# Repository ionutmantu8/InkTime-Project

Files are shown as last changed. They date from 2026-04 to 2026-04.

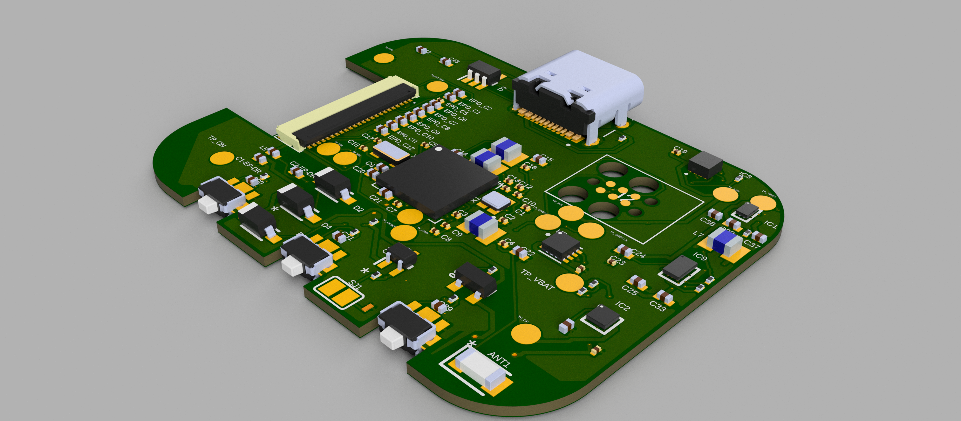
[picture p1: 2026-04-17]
Images/InkTime_3D-PCB_All_3D_1.png

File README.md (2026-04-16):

## Block Diagram
The system is built around the nRF52840 microcontroller, powered from a LiPo battery with USB-C charging, and integrates an e-paper display, IMU, fuel gauge, haptic driver, and three user buttons.

> If the block diagram does not render in your local Markdown viewer, open this file in VS Code and install the **Markdown Preview Mermaid Support** extension.

```mermaid
flowchart LR
    subgraph Power
        USB[USB-C]
        CHG[BQ25180<br/>LiPo Charger]
        BAT[LiPo Battery]
        DCDC[RT6160<br/>DC/DC]
        FG[MAX17048<br/>Fuel Gauge]
    end

    subgraph Core
        MCU[nRF52840]
        ANT[2450AT18B100E<br/>Antenna]
        SWD[SWD Header]
        IMU[BMA421 IMU]
    end

    subgraph Display
        EPDDRV[E-Paper Drive Circuit]
        EPDCONN[503480-2400<br/>E-Paper Connector]
        EPD[E-Paper Display]
    end

    subgraph UI
        BTN[3 Buttons]
        HAPTICDRV[DRV2605<br/>Haptic Driver]
        VIB[Shaker]
    end

    USB --> CHG --> BAT
    BAT --> DCDC
    BAT --> FG
    USB --> MCU
    DCDC --> MCU

    MCU --> ANT
    MCU --> SWD
    MCU <-->|I2C| IMU
    MCU <-->|I2C| FG

    MCU -->|SPI + EPD_CTRL| EPDDRV
    EPDDRV --> EPDCONN --> EPD

    MCU -->|GPIO| BTN
    MCU -->|I2C + HAPTIC_EN| HAPTICDRV
    HAPTICDRV --> VIB
```

## Bill of Materials (BOM)

|Component|JLC Part #|Package|Description|Datasheet|
| :--- | :--- | :--- | :--- | :--- |
|SJ1|N/A|Solder Jumper (Copper feature - leave open)|SMD solder JUMPER|N/A|
|R2, R3, R4|[C3920633](https://www.lcsc.com/product-detail/C3920633.html)|0201|7.68k 0201 Thin Film Surface Mount Fixed Resistor +/-0.5% 0.031W CPF0201D7K68C1|[datasheet](https://wmsc.lcsc.com/wmsc/upload/file/pdf/v2/lcsc/2404081048_TE-Connectivity-CPF0201B511RE1_C3920633.pdf)|
|C23, C27, C34, C42|[C21012218](https://www.lcsc.com/product-detail/C21012218.html)|-|Check availability|[datasheet](https://jlc-prod-smt.oss-eu-central-1.aliyuncs.com/smtDataManualFile/8603520985945550848-C21012218.pdf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)|
|EPD_C5|[C9900156064](https://www.lcsc.com/product-detail/C9900156064.html)|201|Generic chip capacitor|[datasheet](https://ds.yuden.co.jp/TYCOMPAS/or/download?pn=MLAST063SCG681JFNA01&fileType=CA)|
|R1_EP_DR|[C3920633](https://www.lcsc.com/product-detail/C3920633.html)|0201|7.68k 0201 Thin Film Surface Mount Fixed Resistor +/-0.5% 0.031W CPF0201D7K68C1|[datasheet](https://wmsc.lcsc.com/wmsc/upload/file/pdf/v2/lcsc/2404081048_TE-Connectivity-CPF0201B511RE1_C3920633.pdf)|
|C15|[C9900156064](https://www.lcsc.com/product-detail/C9900156064.html)|201|Generic chip capacitor|[datasheet](https://ds.yuden.co.jp/TYCOMPAS/or/download?pn=MLAST063SCG681JFNA01&fileType=CA)|
|C5, C7, C8, C12, C19|[C9900156064](https://www.lcsc.com/product-detail/C9900156064.html)|201|Generic chip capacitor|[datasheet](https://ds.yuden.co.jp/TYCOMPAS/or/download?pn=MLAST063SCG681JFNA01&fileType=CA)|
|C11|[C9900156064](https://www.lcsc.com/product-detail/C9900156064.html)|201|Generic chip capacitor|[datasheet](https://ds.yuden.co.jp/TYCOMPAS/or/download?pn=MLAST063SCG681JFNA01&fileType=CA)|
|R2_EP_DR, R9, R_PWR_EPD|[C3920633](https://www.lcsc.com/product-detail/C3920633.html)|0201|7.68k 0201 Thin Film Surface Mount Fixed Resistor +/-0.5% 0.031W CPF0201D7K68C1|[datasheet](https://wmsc.lcsc.com/wmsc/upload/file/pdf/v2/lcsc/2404081048_TE-Connectivity-CPF0201B511RE1_C3920633.pdf)|
|R5, R7, R8|[C3920633](https://www.lcsc.com/product-detail/C3920633.html)|0201|7.68k 0201 Thin Film Surface Mount Fixed Resistor +/-0.5% 0.031W CPF0201D7K68C1|[datasheet](https://wmsc.lcsc.com/wmsc/upload/file/pdf/v2/lcsc/2404081048_TE-Connectivity-CPF0201B511RE1_C3920633.pdf)|
|C1-EP-DR|[C9900156064](https://www.lcsc.com/product-detail/C9900156064.html)|201|Generic chip capacitor|[datasheet](https://ds.yuden.co.jp/TYCOMPAS/or/download?pn=MLAST063SCG681JFNA01&fileType=CA)|
|C24, C39|[C9900179830](https://www.lcsc.com/product-detail/C9900179830.html)|402|0402 (1005 Metric)|N/A|
|L2|[C12669](https://www.lcsc.com/product-detail/C12669.html)|402|Generic chip inductor|[datasheet](https://www.lcsc.com/datasheet/lcsc_datasheet_2304140030_Murata-Electronics-LQG15HS27NJ02D_C12669.pdf)|
|C1, C2, C17, C18|[C9900156064](https://www.lcsc.com/product-detail/C9900156064.html)|201|Generic chip capacitor|[datasheet](https://ds.yuden.co.jp/TYCOMPAS/or/download?pn=MLAST063SCG681JFNA01&fileType=CA)|
|L3|[C12669](https://www.lcsc.com/product-detail/C12669.html)|402|Generic chip inductor|[datasheet](https://www.lcsc.com/datasheet/lcsc_datasheet_2304140030_Murata-Electronics-LQG15HS27NJ02D_C12669.pdf)|
|C3, C4|[C9900156064](https://www.lcsc.com/product-detail/C9900156064.html)|201|Generic chip capacitor|[datasheet](https://ds.yuden.co.jp/TYCOMPAS/or/download?pn=MLAST063SCG681JFNA01&fileType=CA)|
|C29, C30, C31, C32, C37, C38|[C3920633](https://www.lcsc.com/product-detail/C3920633.html)|0201|7.68k 0201 Thin Film Surface Mount Fixed Resistor +/-0.5% 0.031W CPF0201D7K68C1|[datasheet](https://wmsc.lcsc.com/wmsc/upload/file/pdf/v2/lcsc/2404081048_TE-Connectivity-CPF0201B511RE1_C3920633.pdf)|
|EPD_C1, EPD_C2, EPD_C6, EPD_C7, EPD_C8, EPD_C9, EPD_C10, EPD_C11, EPD_C12|[C9900156064](https://www.lcsc.com/product-detail/C9900156064.html)|201|Generic chip capacitor|[datasheet](https://ds.yuden.co.jp/TYCOMPAS/or/download?pn=MLAST063SCG681JFNA01&fileType=CA)|
|R_TYPE_SEL|[C3920633](https://www.lcsc.com/product-detail/C3920633.html)|0201|7.68k 0201 Thin Film Surface Mount Fixed Resistor +/-0.5% 0.031W CPF0201D7K68C1|[datasheet](https://wmsc.lcsc.com/wmsc/upload/file/pdf/v2/lcsc/2404081048_TE-Connectivity-CPF0201B511RE1_C3920633.pdf)|
|SW_DN, SW_ENT, SW_UP|[C569760](https://www.lcsc.com/product-detail/C569760.html)|SMD,3.9x2.9mm|-40℃~+85℃ 1.6N 1.6mm 15V 2.9mm 20mA 3.9mm 500,000 Cycles IP67 J-Lead Rectangular Button SPST Surface Mount,Vertical White With Bracket SMD,3.9x2.9mm Tactile Switches ROHS|[datasheet](https://wmsc.lcsc.com/wmsc/upload/file/pdf/v2/lcsc/2301111010_PANASONIC-EVPAKE31A_C569760.pdf)|
|Q1|[C2564](https://www.lcsc.com/product-detail/C2564.html)|TO-220AB|-55℃~+175℃ 1 P-Channel 180nC@10V 200W 20mΩ@10V 3.4nF 4V 55V 640pF 74A P-Channel TO-220AB MOSFETs ROHS|[datasheet](https://www.lcsc.com/datasheet/lcsc_datasheet_1809041724_Infineon-Technologies-IRF4905PBF_C2564.pdf)|
|C25, C33|[C9900179830](https://www.lcsc.com/product-detail/C9900179830.html)|402|0402 (1005 Metric)|N/A|
|ANT1|[C2917717](https://www.lcsc.com/product-detail/C2917717.html)|1206|-45℃~+125℃ 0.5dBi 1.3mm 1.6mm 100MHz 2.45GHz 2W 3.2mm 50Ω Patch Antenna 1206 Antennas ROHS|[datasheet](https://www.lcsc.com/datasheet/lcsc_datasheet_2404021210_Johanson-Dielectrics-2450AT18B100E_C2917717.pdf)|
|L1|[C12669](https://www.lcsc.com/product-detail/C12669.html)|402|Generic chip inductor|[datasheet](https://www.lcsc.com/datasheet/lcsc_datasheet_2304140030_Murata-Electronics-LQG15HS27NJ02D_C12669.pdf)|
|X2|[C32346](https://www.lcsc.com/product-detail/C32346.html)|SMD3215-2P|-40℃~+85℃ 12.5pF 32.768kHz 70kΩ Crystal Oscillator ±20ppm SMD3215-2P Crystals ROHS|[datasheet](https://www.lcsc.com/datasheet/lcsc_datasheet_2404180925_Seiko-Epson-Q13FC13500004_C32346.pdf)|
|X1|[C9009](https://www.lcsc.com/product-detail/C9009.html)|SMD3225-4P|-40℃~+85℃ 12pF 32MHz Crystal Oscillator ±10ppm ±20ppm SMD3225-4P Crystals ROHS|[datasheet](https://www.lcsc.com/datasheet/lcsc_datasheet_2403291504_YXC-Crystal-Oscillators-X322532MOB4SI_C9009.pdf)|
|R17, R18|[C3920633](https://www.lcsc.com/product-detail/C3920633.html)|0201|7.68k 0201 Thin Film Surface Mount Fixed Resistor +/-0.5% 0.031W CPF0201D7K68C1|[datasheet](https://wmsc.lcsc.com/wmsc/upload/file/pdf/v2/lcsc/2404081048_TE-Connectivity-CPF0201B511RE1_C3920633.pdf)|
|C43|[C9900156064](https://www.lcsc.com/product-detail/C9900156064.html)|201|Generic chip capacitor|[datasheet](https://ds.yuden.co.jp/TYCOMPAS/or/download?pn=MLAST063SCG681JFNA01&fileType=CA)|
|C2-EP-DR|[C9900156064](https://www.lcsc.com/product-detail/C9900156064.html)|201|Generic chip capacitor|[datasheet](https://ds.yuden.co.jp/TYCOMPAS/or/download?pn=MLAST063SCG681JFNA01&fileType=CA)|
|C6, C14, C20, C21|[C9900156064](https://www.lcsc.com/product-detail/C9900156064.html)|201|Generic chip capacitor|[datasheet](https://ds.yuden.co.jp/TYCOMPAS/or/download?pn=MLAST063SCG681JFNA01&fileType=CA)|
|C16|[C9900156064](https://www.lcsc.com/product-detail/C9900156064.html)|201|Generic chip capacitor|[datasheet](https://ds.yuden.co.jp/TYCOMPAS/or/download?pn=MLAST063SCG681JFNA01&fileType=CA)|
|J1|[C122434](https://www.lcsc.com/product-detail/C122434.html)|SMD,P=0.5mm,Surface Mount，Right Angle|FFC & FPC Connectors 0.5mm FPC RA SMT Dual Contact 24Ckt|[datasheet](https://www.molex.com/content/dam/molex/molex-dot-com/products/automated/en-us/salesdrawingpdf/503/503480/5034802400_sd.pdf)|
|R1_USB, R2_USB|[C3920633](https://www.lcsc.com/product-detail/C3920633.html)|0201|7.68k 0201 Thin Film Surface Mount Fixed Resistor +/-0.5% 0.031W CPF0201D7K68C1|[datasheet](https://wmsc.lcsc.com/wmsc/upload/file/pdf/v2/lcsc/2404081048_TE-Connectivity-CPF0201B511RE1_C3920633.pdf)|
|L5|[C1329646](https://www.lcsc.com/product-detail/C1329646.html)|SMD,4.8x4.8mm|1.6A 1.6A 4.7uH 41.4mΩ AEC-Q200 ±30% SMD,4.8x4.8mm Power Inductors ROHS|[datasheet](https://wmsc.lcsc.com/wmsc/upload/file/pdf/v2/lcsc/2304140030_BOURNS-SRR4828A-4R7Y_C1329646.pdf)|
|C9|[C9900156064](https://www.lcsc.com/product-detail/C9900156064.html)|201|Generic chip capacitor|[datasheet](https://ds.yuden.co.jp/TYCOMPAS/or/download?pn=MLAST063SCG681JFNA01&fileType=CA)|
|IC3|[C189517](https://www.lcsc.com/product-detail/C189517.html)|LGA-12(2x2)|Accelerometers Triaxial low-g 12bit Acceleration Sensor|[datasheet](https://www.lcsc.com/datasheet/C189517.pdf)|
|IC1|[C3682423](https://www.lcsc.com/product-detail/C3682423.html)|DSBGA-8(1.1x1.6)|Charger IC Lithium Ion/Polymer, Lithium Iron Phosphate 8-DSBGA (1.6x1.1)|[datasheet](https://www.ti.com/cn/lit/ds/symlink/bq25180.pdf?ts=1775594237116)|
|IC2|[C81079](https://www.lcsc.com/product-detail/C81079.html)|DSBGA-9|Haptic Driver for ERM/LRA with Built-In Library and Smart Loop Architecture|[datasheet](https://www.ti.com/cn/lit/gpn/drv2605)|
|L7|[C5832368](https://www.lcsc.com/product-detail/C5832368.html)|1008|13mΩ 470nH 6.5A 7.5A ±20% 1008 Power Inductors ROHS|[datasheet](https://wmsc.lcsc.com/wmsc/upload/file/pdf/v2/lcsc/2306021632_cjiang--Changjiang-Microelectronics-Tech-FTC252012SR47MBCA_C5832368.pdf)|
|TP (Test Pads)|N/A|N/A|Test pad|N/A|
|J4|[C709357](https://www.lcsc.com/product-detail/C709357.html)|SMD|-40℃~+85℃ 1 10,000 cycles 16P 30V 3A 7.81mm Female Surface Mount, Right Angle Type-C SMD USB Connectors ROHS|[datasheet](https://www.lcsc.com/datasheet/lcsc_datasheet_2404191039_Shenzhen-Kinghelm-Elec-KH-TYPE-C-16P_C709357.pdf)|
|U2|[C2682616](https://www.lcsc.com/product-detail/C2682616.html)|DFN-8-EP(2x2)|-40℃~+85℃ 1 2.5V~4.5V 3uA I2C Lithium Battery DFN-8-EP(2x2) Battery Management ROHS|[datasheet](https://www.lcsc.com/datasheet/lcsc_datasheet_2410121738_Analog-Devices-Inc--Maxim-Integrated-MAX17048G-T10_C2682616.pdf)|
|D2, D4, D5|[C82046](https://www.lcsc.com/product-detail/C82046.html)|SOD-123|ON SEMICONDUCTOR - MBR0530 - DIODE, SCHOTTKY, 0.5A, 30V, SOD-123|[datasheet](https://www.lcsc.com/datasheet/lcsc_datasheet_2304140030_onsemi-MBR0530T1G_C82046.pdf)|
|C10, C13, C22|[C9900156064](https://www.lcsc.com/product-detail/C9900156064.html)|201|Generic chip capacitor|[datasheet](https://ds.yuden.co.jp/TYCOMPAS/or/download?pn=MLAST063SCG681JFNA01&fileType=CA)|
|U1|[C3606653](https://www.lcsc.com/product-detail/C3606653.html)|QFN-48(6x6)|nRF52840|[datasheet](https://www.lcsc.com/datasheet/C3606653.pdf)|
|IC9|[C7065276](https://www.lcsc.com/product-detail/C7065276.html)|WLCSP-15B(2.3x1.4)|Buck-Boost Regulator Positive Output Step-Up/Step-Down I2C DC-DC Controller IC 15-WL-CSP (BSC) (1.4x2.3)|[datasheet](https://wmsc.lcsc.com/wmsc/upload/file/pdf/v2/lcsc/2312271436_Richtek-Tech-RT6160AWSC_C7065276.pdf)|
|Q3|[C469327](https://www.lcsc.com/product-detail/C469327.html)|SOT-323|MOSFET N-Ch 30V 1.5A TrenchFET SC70 Vishay Si1308EDL-T1-GE3 N-channel MOSFET Transistor, 1.5 A, 30 V, 3-Pin SC-70|[datasheet](https://www.lcsc.com/datasheet/lcsc_datasheet_1912202016_Vishay-Intertech-SI1308EDL-T1-GE3_C469327.pdf)|
|J2|[C90533](https://www.lcsc.com/product-detail/C90533.html)|P=1mm|CABLE ADAPTER 6 POS|[datasheet](https://wmsc.lcsc.com/wmsc/upload/file/pdf/v2/lcsc/1810141506_LX-FFC6P1-0mm7CM_C90533.pdf)|
|D3|[C2969755](https://www.lcsc.com/product-detail/C2969755.html)|SOT-23-6L|Low Cap. ESD Protection Auto SOT-23-6 STMicroelectronics USBLC6-2SC6Y, Dual Uni-Directional TVS Diode Array, 6-Pin SOT-23|[datasheet](https://wmsc.lcsc.com/wmsc/upload/file/pdf/v2/lcsc/2211080730_STMicroelectronics-USBLC6-2SC6Y_C2969755.pdf)|

## Hardware Functionality

The hardware platform is built around the **Nordic nRF52840** microcontroller, which acts as the central processing and communication unit of the device. The system integrates power-management circuitry, an inertial sensor, an e-paper display subsystem, a haptic feedback subsystem, USB connectivity, user input buttons, and a debug interface.

### Main hardware blocks

#### 1. Microcontroller – nRF52840
The nRF52840 is the core of the system. It was chosen because it provides:
- low-power operation, suitable for battery-powered wearable devices;
- a rich set of GPIOs;
- integrated USB device support;
- SPI and I2C peripherals for connecting multiple external components;
- SWD debug support;
- BLE capability for future wireless extensions.

The MCU is clocked using:
- a **32 MHz crystal** for the main system clock;
- a **32.768 kHz crystal** for accurate low-power timing.

It also includes the RF matching network and a **2.4 GHz chip antenna** for wireless communication.

---

#### 2. Power subsystem
The device is powered from a **single-cell LiPo battery** and charged through a **USB-C connector**.

The power architecture contains:
- **USB-C connector** for power input and USB communication;
- **USBLC6-2SC6Y** ESD protection for the USB data lines;
- **BQ25180YBGR** battery charger / PMIC for LiPo charging and battery power management;
- **RT6160AWSC** DC/DC converter for generating the regulated supply rail;
- decoupling capacitors and inductors used for filtering and rail stabilization;
- **MAX17048G+T10** fuel gauge for battery level monitoring.

This architecture allows the system to be powered both from USB and from battery, while also monitoring the battery state and keeping energy consumption low.

---

#### 3. E-paper display subsystem
The user interface is based on a **1.54-inch e-paper display**, connected through an FPC connector (**503480-2400**).  
Because the display requires dedicated bias voltages, the design also includes an **e-paper drive circuit** built from passive components, Schottky diodes, MOSFETs and filtering capacitors.

The display subsystem uses:
- **SPI signals** for communication with the MCU;
- several digital control signals:
  - `EPD_CS`
  - `EPD_DC`
  - `EPD_RST`
  - `EPD_BUSY`

The e-paper display was chosen because it has very low static power consumption and is well suited for wearable devices that only update the screen occasionally.

---

#### 4. IMU subsystem
Motion sensing is implemented using the **BMA421 IMU**.  
This sensor communicates with the MCU over **I2C** and provides interrupt outputs:
- `IMU_INT1`
- `IMU_INT2`

The IMU is used for motion/activity awareness and can wake or notify the MCU when specific events occur.

---

#### 5. Battery monitoring
Battery state measurement is handled by the **MAX17048 fuel gauge**, which communicates over **I2C** and provides an `ALERT` line to the MCU.  
This allows the firmware to estimate battery percentage and detect low-battery conditions.

---

#### 6. Haptic feedback
The haptic subsystem is built around the **DRV2605YZFR** haptic driver, connected to the MCU over **I2C**.  
The driver controls the vibration motor (shaker) through:
- `SDA`
- `SCL`
- `HAPTIC_EN`

This solution was chosen because it offloads waveform generation from the microcontroller and allows reliable control of the vibration motor.

---

#### 7. User buttons
The device includes **three buttons**:
- `SW_UP`
- `SW_ENT`
- `SW_DN`

These are connected to dedicated GPIO inputs of the MCU and provide the basic user interface for navigation and interaction.

---

#### 8. Debug and programming
For firmware upload and debugging, the board includes a **TC2030-IDC SWD header**.  
The exposed debug signals are:
- `SWDIO`
- `SWDCLK`
- `SWO`
- `RESET`
- `3.3V`
- `GND`

This header is used during development and testing.

---

## Interfaces used in the design

The design uses the following communication interfaces:

- **USB**
  - used for wired connectivity and battery charging path integration;
  - signals used: `VBUS`, `D+`, `D-`.

- **I2C**
  - shared bus used for:
    - BMA421 IMU
    - MAX17048 fuel gauge
    - DRV2605 haptic driver

- **SPI**
  - used for communication with the e-paper display subsystem

- **GPIO**
  - used for:
    - buttons
    - display control lines
    - interrupt lines
    - enable lines

- **SWD**
  - used for debugging and programming the nRF52840

---

## nRF52840 Pin Usage

Based on the schematic, the following nRF52840 pins are used for the main peripherals:

| nRF52840 Pin | Signal | Connected block | Purpose |
|---|---|---|---|
| P0.13 | D+ | USB-C | USB data line |
| P0.14 | D- | USB-C | USB data line |
| VBUS pin | VBUS | USB-C / charger | USB voltage detection |
| P0.06 | SDA | I2C bus | Shared data line for IMU, fuel gauge and haptic driver |
| P0.07 | SCL | I2C bus | Shared clock line for IMU, fuel gauge and haptic driver |
| P1.13 | MOSI | E-paper display | SPI data output to display |
| P1.15 | SCK | E-paper display | SPI clock |
| P0.17 | EPD_RST | E-paper display | Display reset |
| P0.15 | EPD_BUSY | E-paper display | Busy/status feedback from display |
| P0.16 | EPD_DC | E-paper display | Data/command select |
| P0.05 | EPD_CS | E-paper display | SPI chip select |
| P0.08 | IMU_INT1 | IMU | Interrupt from IMU |
| P1.08 | IMU_INT2 | IMU | Second interrupt from IMU |
| P0.11 | PMIC_INT | BQ25180 | Power-management interrupt |
| P0.24 | ALERT | MAX17048 | Battery fuel gauge alert |
| P0.12 | HAPTIC_EN | DRV2605 | Haptic driver enable/control |
| SWDIO | SWDIO | SWD header | Debug/programming |
| SWDCLK | SWDCLK | SWD header | Debug/programming |
| P0.18 / RESET | RESET | SWD header | Hardware reset |
| P1.09 | SWO | SWD header | Debug trace output |
| ANT pin | RF | Antenna matching network | 2.4 GHz RF connection |

### Why these pins were chosen
The chosen pin mapping follows the functional requirements of the peripherals:
- the dedicated **USB pins** of the nRF52840 are used for `D+` and `D-`;
- the e-paper display uses a mix of **SPI pins** and additional GPIO control lines;
- the sensors and monitoring ICs share the same **I2C bus**, which reduces routing complexity and saves GPIOs;
- interrupt-capable GPIOs are used for `IMU_INT1`, `IMU_INT2`, `PMIC_INT`, and `ALERT`;
- `SWDIO`, `SWDCLK`, `RESET`, and `SWO` are routed to the debug header for easier firmware development.

---

## Power Consumption Considerations

The board was designed with low-power operation in mind.

### Main power-saving choices
- **nRF52840** is a low-power MCU suitable for battery-powered applications.
- **E-paper display** only consumes significant power during refresh; static content does not require continuous display power like an LCD.
- **BQ25180** integrates battery charging and PMIC functionality, reducing the need for discrete always-on circuitry.
- **MAX17048** provides battery estimation with low overhead.
- **I2C shared bus** reduces pin count and simplifies routing.
- The **haptic motor** is driven only when needed.
- Buttons are connected as low-duty-cycle GPIO inputs.
- The external DC/DC stage improves efficiency compared to a purely linear power architecture.

### Qualitative consumption profile
The highest instantaneous consumption occurs during:
- battery charging over USB;
- e-paper refresh;
- vibration motor activation;
- radio activity of the nRF52840.

The lowest consumption mode is expected when:
- the display content is static,
- the MCU is in sleep mode,
- haptic feedback is off,
- no USB power is connected,
- only low-power monitoring remains active.

This makes the platform appropriate for a compact wearable device where energy efficiency matters more than continuous high-performance operation.

## ERC / Schematic Checks

During schematic verification, the project generated a small number of ERC warnings and one input-pin related message. These were reviewed manually before approval.

### Input-pin / single-pin style warnings
Warnings such as:
- `Only INPUT pins on net ...`
- `Only one pin on net ...`

were approved because, according to the project requirements and the lab guidance, these checks can be accepted when the designer has manually verified that the connections are intentional and that no required schematic connections are missing. In this design, the affected nets were inspected and no missing functional connection was identified.

### Power-pin warnings
Warnings of the form:
- `POWER pin ... connected to ...`

were also reviewed manually. After checking the schematic against the intended design, no missing supply rails or broken power connections were found. In addition, this was discussed during the lab, and we were told that such warnings can be approved when the power connectivity is intentional and complete.

## ERC Notes
Some ERC warnings were approved after manual verification. The `Only INPUT pins on net ...` and similar messages were accepted because the affected nets were intentionally connected and no functional connection was missing from the schematic. The power-pin warnings were also checked manually and approved after confirming that the supply rails and power connections were correct.

## DRC Notes
Some DRC warnings were approved in the PCB layout, mainly overlap-related messages such as SMD-via or pad-via overlaps. These were caused intentionally by using via-in-pad / escape routing in dense areas of the board, where this approach was necessary to complete routing in the available space.

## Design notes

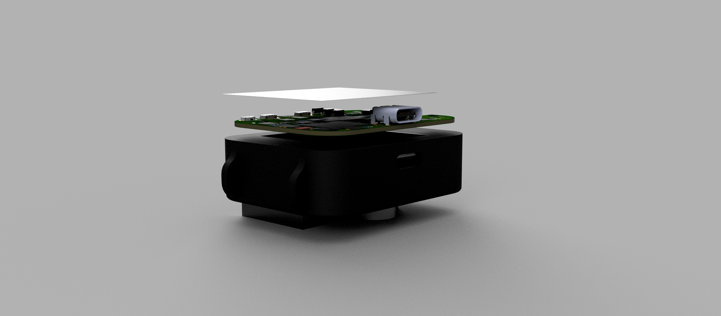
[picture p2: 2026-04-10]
Images/Exploaded_View_Pic.png

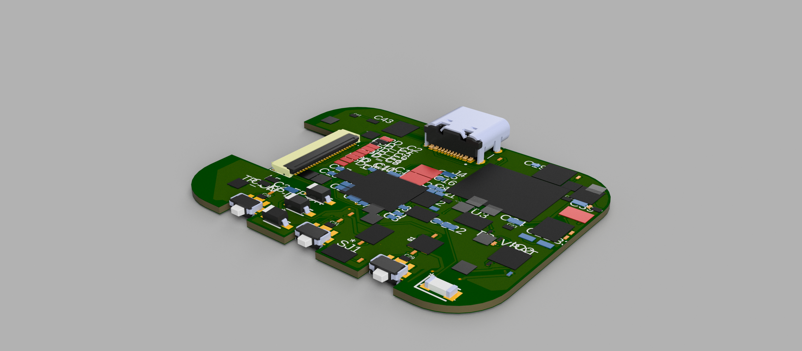
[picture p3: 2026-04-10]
Images/Board_1.png

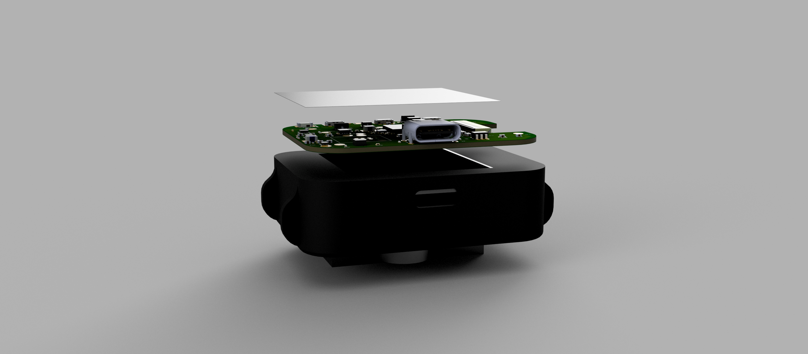
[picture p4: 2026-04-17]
Images/InkTime_Complete_Device_Exploaded_View.png

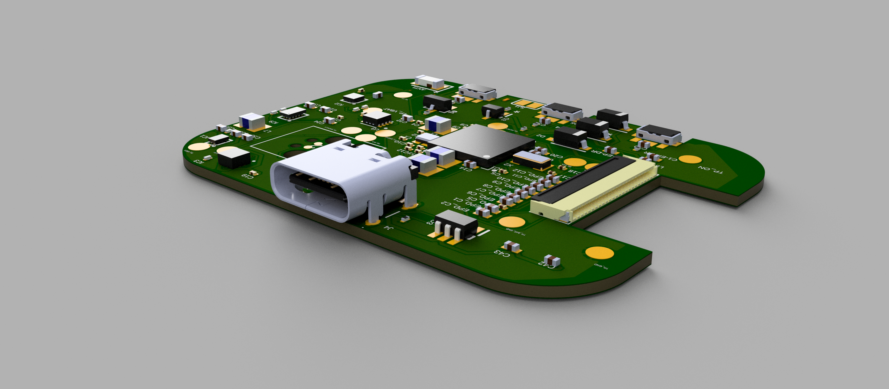
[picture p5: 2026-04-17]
Images/InkTime_3D-PCB_All_3D_2.png

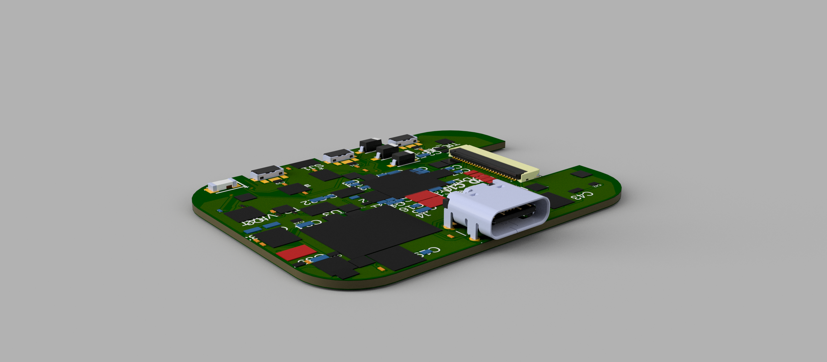
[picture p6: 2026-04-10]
Images/Board_2.png

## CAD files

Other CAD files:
Mechanical/InkTime_Complete_Device.f3z

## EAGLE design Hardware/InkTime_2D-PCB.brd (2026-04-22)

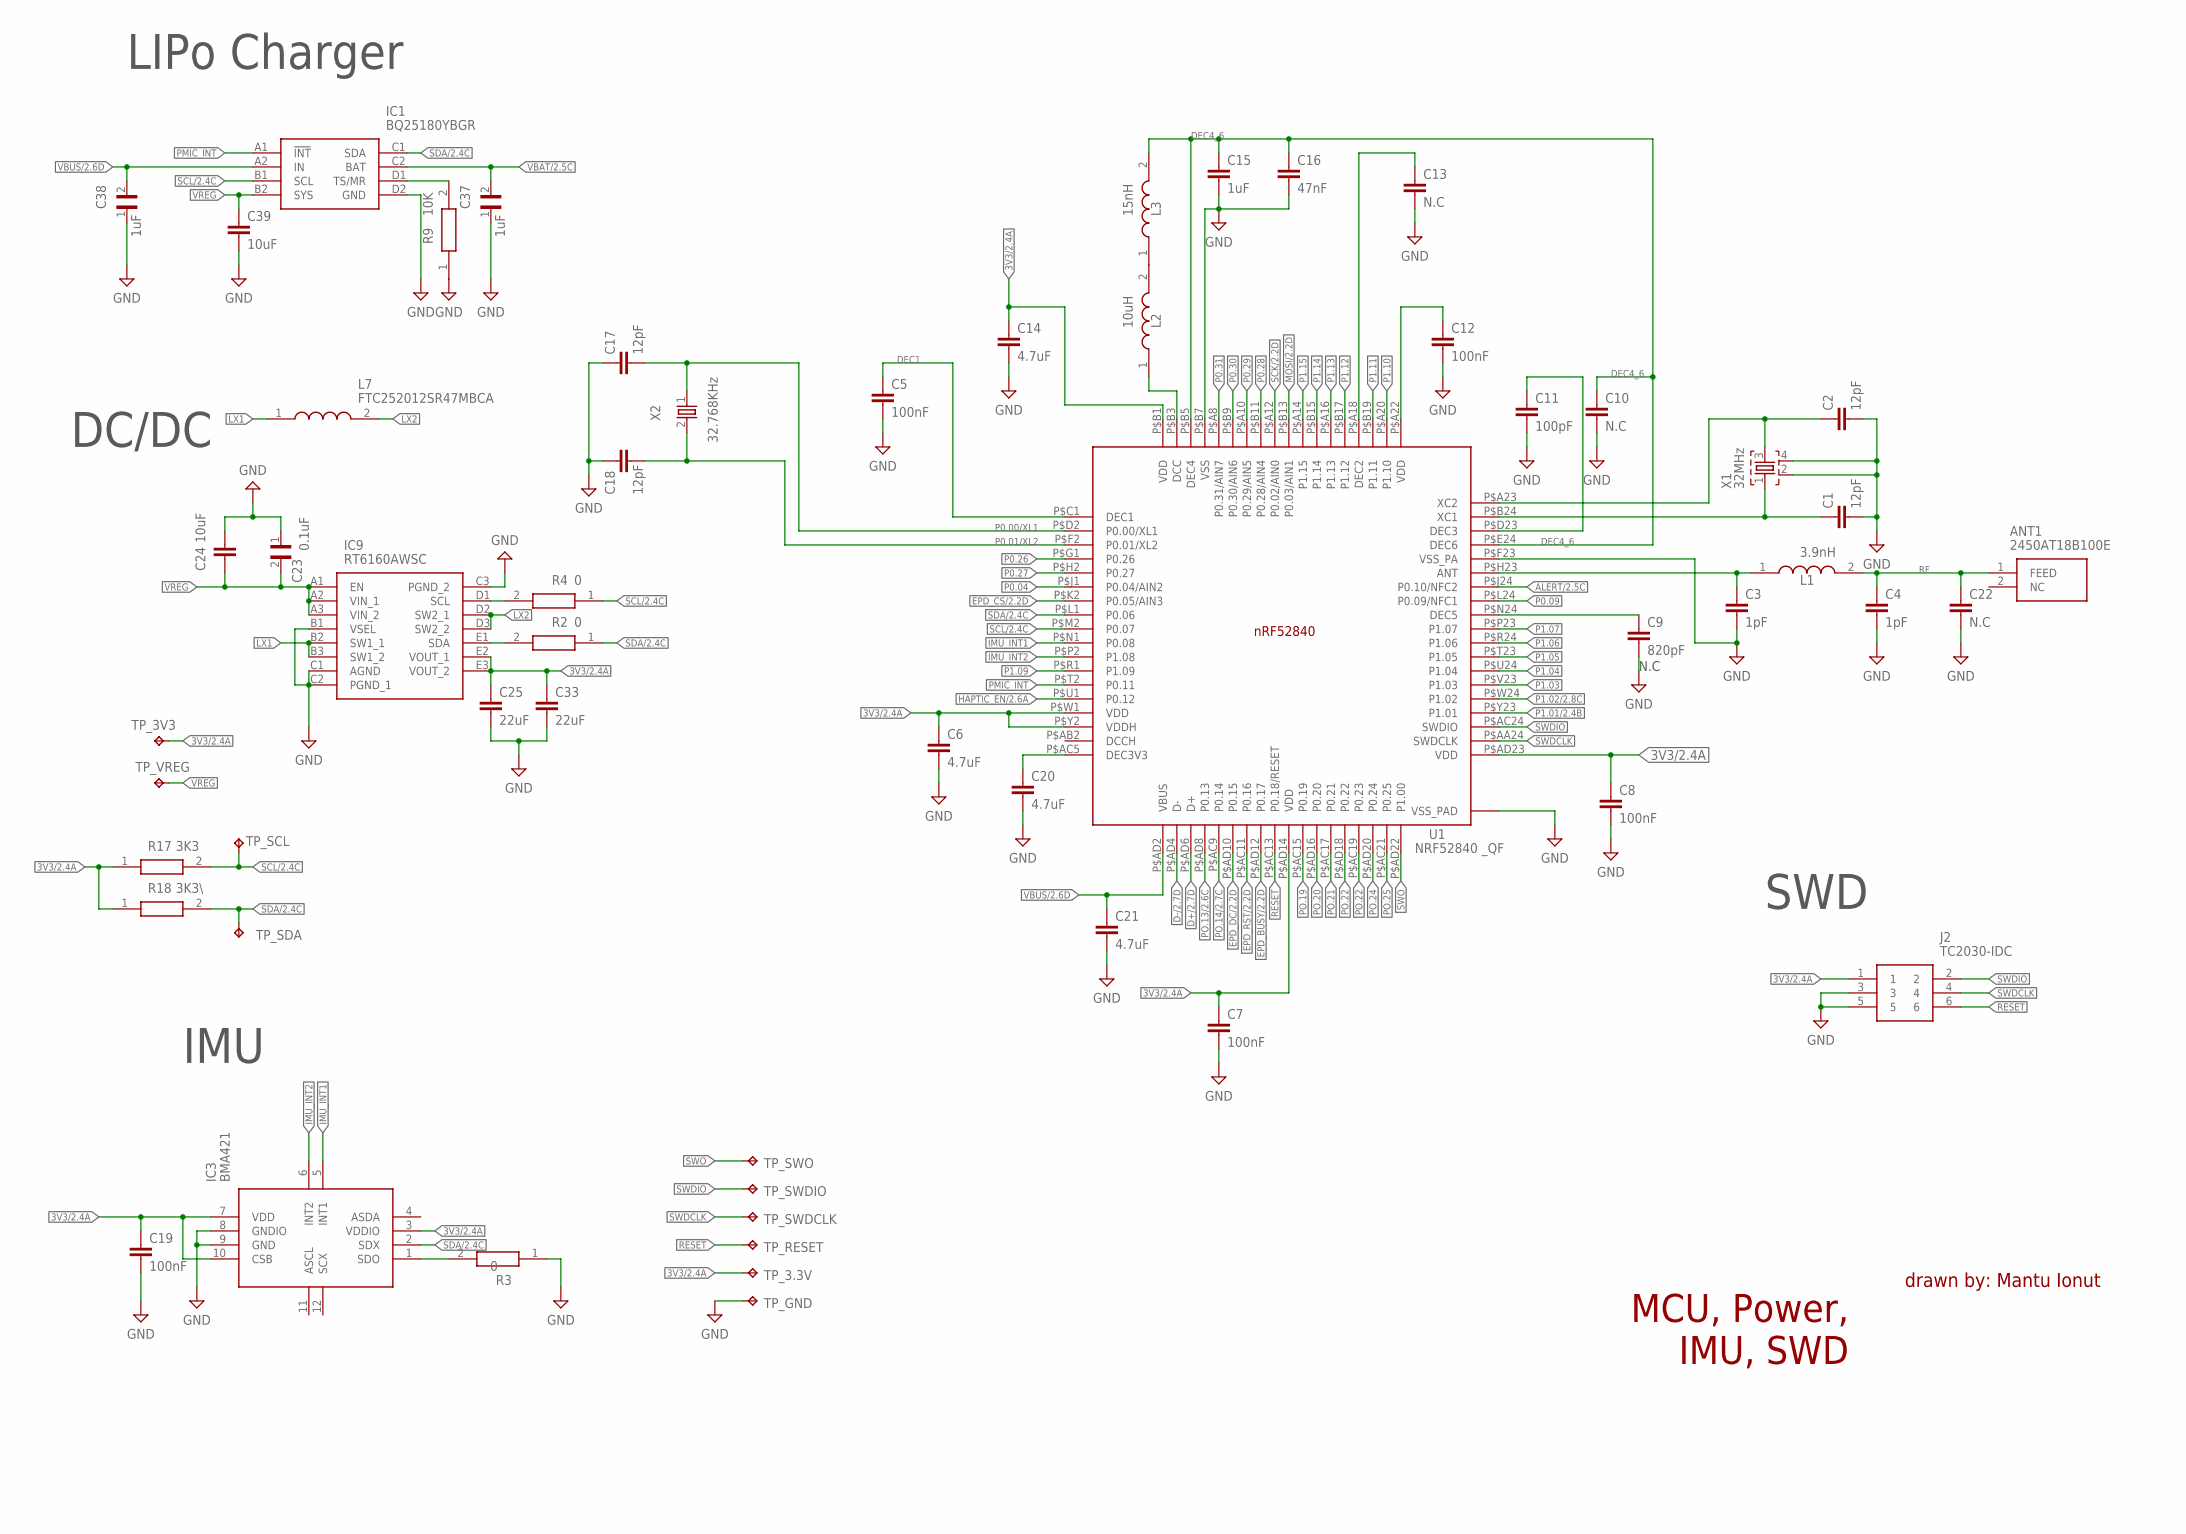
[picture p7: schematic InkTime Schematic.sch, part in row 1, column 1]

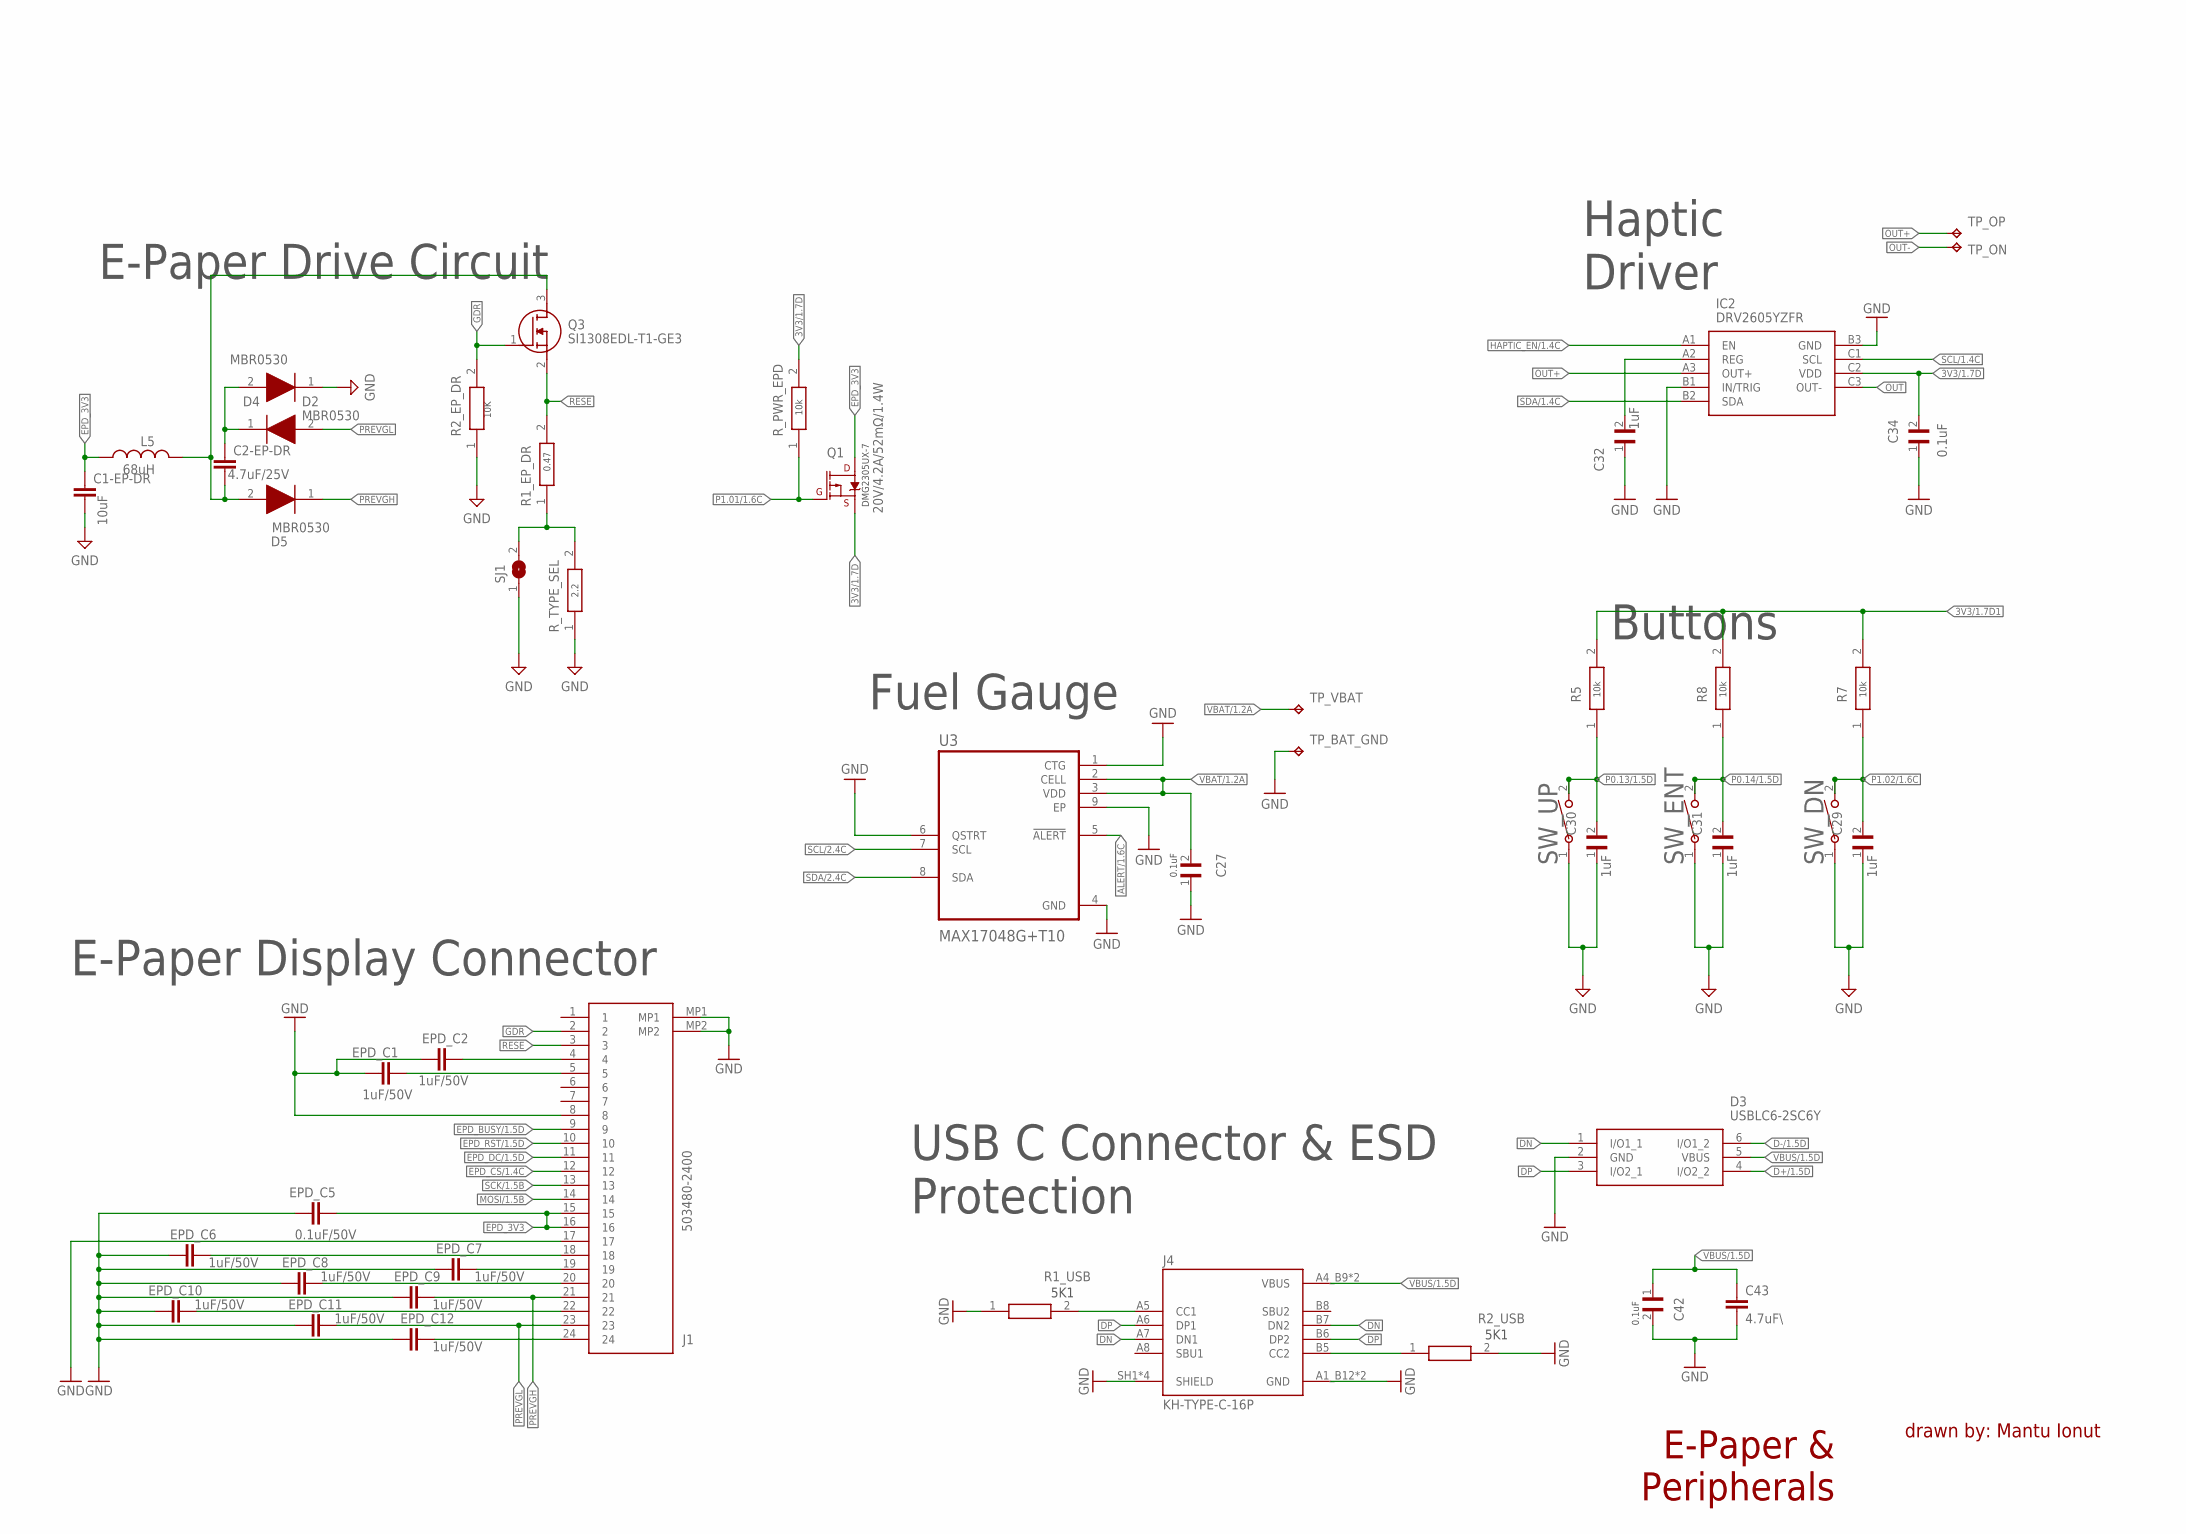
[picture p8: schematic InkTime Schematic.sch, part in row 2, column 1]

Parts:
ANT1: 2450AT18B100E; 2450AT18B100E_ANTC3216X140N
C1, C2, C17, C18: 12pF; NORDIC_NRF_3_RESC0201_L
C1-EP-DR, C24, C39: 10uF; NORDIC_NRF_3_RESC0402_L
C2-EP-DR: 4.7uF/25V; NORDIC_NRF_3_RESC0402_L
C3, C4: 1pF; NORDIC_NRF_3_RESC0201_L
C5, C7, C8, C12, C19: 100nF; NORDIC_NRF_3_RESC0201_L
C6, C14, C20, C21: 4.7uF; NORDIC_NRF_3_RESC0402_L
C9: 820pF; NORDIC_NRF_3_RESC0201_L
C10, C13: N.C; NORDIC_NRF_3_RESC0201_L
C11: 100pF; NORDIC_NRF_3_RESC0201_L
C15: 1uF; NORDIC_NRF_3_RESC0402_L
C16: 47nF; NORDIC_NRF_3_RESC0201_L
C22: N.C; NORDIC_NRF_3_RESC0402_L
C23, C42: 0.1uF; GRM011R60J152KE01L_2_CAPC0201X13N
C25, C33: 22uF; NORDIC_NRF_3_RESC0402_L
C27, C34: 0.1uF; GRM011R60J152KE01L_1_0201
C29, C30, C31, C37, C38: 1uF; GRM011R60J152KE01L_2_CAPC0201X13N
C32: 1uF; GRM011R60J152KE01L_1_0201
C43: 4.7uF\; NORDIC_NRF_3_RESC0402_L
D2, D4, D5: MBR0530; ESP32_C6_LIBRARY_5_SOD3716X135N
D3: USBLC6-2SC6Y; ESP32_C6_LIBRARY_3_SOT95P280X145-6N
EPD_C1, EPD_C2, EPD_C6, EPD_C7, EPD_C8, EPD_C9, EPD_C10, EPD_C11, EPD_C12: 1uF/50V; NORDIC_NRF_3_RESC0402_L
EPD_C5: 0.1uF/50V; NORDIC_NRF_3_RESC0201_L
IC1: BQ25180YBGR; BQ25180YBGR_BGA8C40P2X4_100X155X50
IC2: DRV2605YZFR; DRV2605YZFR_BGA9C50P3X3_144X144X62
IC3: BMA421; BMA423_BMA423
IC9: RT6160AWSC; RT6160AWSC_BGA15C40P3X5_140X230X60
J1: 503480-2400; 503480-2400_5034802400
J2: TC2030-IDC; TC2030-IDC_TC2030IDC
J4: KH-TYPE-C-16P; KH-TYPE-C-16P_KINGHELM_KH-TYPE-C-16P
L1: 3.9nH; MLP2016SR47MT0S1_INDC2016X100N
L2: 10uH; MLP2016SR47MT0S1_INDC2016X100N
L3: 15nH; MLP2016SR47MT0S1_INDC2016X100N
L5: 68uH; NORDIC_NRF_2_RESC0402_L
L7: FTC252012SR47MBCA; MLP2016SR47MT0S1_INDC2016X100N
Q1: 20V/4.2A/52mΩ/1.4W; ESP32_C6_LIBRARY_4_ESP32_C6_LIBRARY_4_ESP32_C6_LIBRARY_4_ES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
Q3: SI1308EDL-T1-GE3; ESP32_C6_LIBRARY_6_SOT65P210X110-3N
R1_EP_DR: 0.47; CPF0201D7K68C1_0201
R1_USB, R2_USB: 5K1; CPF0201D7K68C1_0201
R2, R3, R4: 0; CPF0201D7K68C1_0201
R2_EP_DR, R5, R7, R8, R9: 10K; CPF0201D7K68C1_0201
R17: 3K3; CPF0201D7K68C1_0201
R18: 3K3\; CPF0201D7K68C1_0201
R_PWR_EPD: 10K; CPF0201D7K68C1_0201
R_TYPE_SEL: 2.2; CPF0201D7K68C1_0201
SJ1: 0; ESP32_C6_LIBRARY_7_JUMPER_SJ
SW_DN: 2025-10-22_07-23-44_LIBRARY_EVP-AKE31ASW_EVP-AKE3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; 2025-10-22_07-23-44_LIBRARY_SW_EVP-AKE31A_PAN
SW_ENT: 2025-10-22_07-23-44_LIBRARY_EVP-AKE31ASW_EVP-AKE3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; 2025-10-22_07-23-44_LIBRARY_SW_EVP-AKE31A_PAN
SW_UP: 2025-10-22_07-23-44_LIBRARY_EVP-AKE31ASW_EVP-AKE3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; 2025-10-22_07-23-44_LIBRARY_SW_EVP-AKE31A_PAN
TP_3.3V, TP_3V3: HECTOR_WATCH_1_TPTP20R; HECTOR_WATCH_1_TP20R
TP_BAT_GND: HECTOR_WATCH_1_TPTP20R; HECTOR_WATCH_1_TP20R
TP_GND: HECTOR_WATCH_1_TPTP20R; HECTOR_WATCH_1_TP20R
TP_ON: HECTOR_WATCH_1_TPTP20R; HECTOR_WATCH_1_TP20R
TP_OP: HECTOR_WATCH_1_TPTP20R; HECTOR_WATCH_1_TP20R
TP_RESET: HECTOR_WATCH_1_TPTP20R; HECTOR_WATCH_1_TP20R
TP_SCL: HECTOR_WATCH_1_TPTP20R; HECTOR_WATCH_1_TP20R
TP_SDA: HECTOR_WATCH_1_TPTP20R; HECTOR_WATCH_1_TP20R
TP_SWDCLK: HECTOR_WATCH_1_TPTP20R; HECTOR_WATCH_1_TP20R
TP_SWDIO: HECTOR_WATCH_1_TPTP20R; HECTOR_WATCH_1_TP20R
TP_SWO: HECTOR_WATCH_1_TPTP20R; HECTOR_WATCH_1_TP20R
TP_VBAT: HECTOR_WATCH_1_TPTP20R; HECTOR_WATCH_1_TP20R
TP_VREG: HECTOR_WATCH_1_TPTP20R; HECTOR_WATCH_1_TP20R
U1: NRF52840 _QF; NORDIC_NRF_4_AQFN50P700X700X85_HS-74N
U3: MAX17048G+T10; ESP32_C6_LIBRARY_SON50P200X200X80-9N
X1: 32MHz; NORDIC_NRF_BT-XTAL_2016_N
X2: 32.768KHz; NORDIC_NRF_1_XTAL_3215_N

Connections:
3V3/1.7D: C34.2, IC2.C2 (VDD), Q1.2 (S), R_PWR_EPD.2
3V3/1.7D1: R5.2, R7.2, R8.2
3V3/2.4A: C6.1, C7.1, C8.1, C19.1, C25.1, C33.1, IC3.3 (VDDIO), IC3.7 (VDD), IC3.10 (CSB), IC9.E2 (VOUT_1), IC9.E3 (VOUT_2), J2.1, TP_3.3V.TP, TP_3V3.TP, U1.P$AD14 (VDD), U1.P$AD23 (VDD), U1.P$W1 (VDD), U1.P$Y2 (VDDH)
ALERT/1.6C: U3.5 (!ALERT)
ALERT/2.5C: U1.P$J24 (P0.10/NFC2)
D+/1.5D: D3.4 (I/O2_2)
D+/2.7D: U1.P$AD6 (D+)
D-/1.5D: D3.6 (I/O1_2)
D-/2.7D: U1.P$AD4 (D-)
DEC1: C5.1, U1.P$C1 (DEC1)
DEC4_6: C10.1, C15.1, C16.1, L3.2, U1.P$B5 (DEC4), U1.P$E24 (DEC6)
DN: D3.1 (I/O1_1), J4.A7 (DN1), J4.B7 (DN2)
DP: D3.3 (I/O2_1), J4.A6 (DP1), J4.B6 (DP2)
EPD_3V3: C1-EP-DR.1, EPD_C5.2, J1.15, J1.16, L5.1, Q1.3 (D)
EPD_BUSY/1.5D: J1.9
EPD_BUSY/2.2D: U1.P$AD12 (P0.17)
EPD_CS/1.4C: J1.12
EPD_CS/2.2D: U1.P$K2 (P0.05/AIN3)
EPD_DC/1.5D: J1.11
EPD_DC/2.2D: U1.P$AD10 (P0.15)
EPD_RST/1.5D: J1.10
EPD_RST/2.2D: U1.P$AC11 (P0.16)
GDR: J1.2, Q3.1 (G), R2_EP_DR.2
GND: C1.2, C1-EP-DR.2, C2.2, C3.2, C4.2, C5.2, C6.2, C7.2, C8.2, C9.2, C10.2, C11.2, C12.2, C13.2, C14.2, C15.2, C16.2, C17.1, C18.1, C19.2, C20.2, C21.2, C22.2, C23.1, C24.1, C25.2, C27.1, C29.1, C30.1, C31.1, C32.1, C33.2, C34.1, C37.1, C38.1, C39.2, C42.2, C43.2, D3.2 (GND), D4.1 (K), EPD_C1.1, EPD_C2.1, EPD_C5.1, EPD_C6.1, EPD_C7.1, EPD_C8.1, EPD_C9.1, EPD_C10.1, EPD_C11.1, EPD_C12.1, IC1.D2 (GND), IC2.B1 (IN/TRIG), IC2.B3 (GND), IC3.8 (GNDIO), IC3.9 (GND), IC9.B1 (VSEL), IC9.C1 (AGND), IC9.C2 (PGND_1), IC9.C3 (PGND_2), J1.8, J1.17, J1.MP1, J1.MP2, J2.3, J2.5, J4.A1_B12 (GND), J4.A12_B1 (GND), J4.SH1 (SHIELD), J4.SH2 (SHIELD), J4.SH3 (SHIELD), J4.SH4 (SHIELD), R1_USB.1, R2_EP_DR.1, R2_USB.2, R3.1, R9.1, R_TYPE_SEL.1, SJ1.1, SW_DN.1, SW_ENT.1, SW_UP.1, TP_BAT_GND.TP, TP_GND.TP, U1.P$74 (VSS_PAD), U1.P$75 (VSS_PAD), U1.P$76 (VSS_PAD), U1.P$77 (VSS_PAD), U1.P$78 (VSS_PAD), U1.P$79 (VSS_PAD), U1.P$80 (VSS_PAD), U1.P$81 (VSS_PAD), U1.P$82 (VSS_PAD), U1.P$83 (VSS_PAD), U1.P$84 (VSS_PAD), U1.P$85 (VSS_PAD), U1.P$86 (VSS_PAD), U1.P$87 (VSS_PAD), U1.P$88 (VSS_PAD), U1.P$89 (VSS_PAD), U1.P$90 (VSS_PAD), U1.P$B7 (VSS), U1.P$F23 (VSS_PA), U3.1 (CTG), U3.4 (GND), U3.6 (QSTRT), U3.9 (EP), X1.2, X1.4
HAPTIC_EN/1.4C: IC2.A1 (EN)
HAPTIC_EN/2.6A: U1.P$U1 (P0.12)
IMU_INT1: IC3.5 (INT1), U1.P$N1 (P0.08)
IMU_INT2: IC3.6 (INT2), U1.P$P2 (P1.08)
LX1: IC9.B2 (SW1_1), IC9.B3 (SW1_2), L7.1
LX2: IC9.D2 (SW2_1), IC9.D3 (SW2_2), L7.2
MOSI/1.5B: J1.14
MOSI/2.2D: U1.P$B13 (P0.03/AIN1)
unnamed: C11.1, U1.P$D23 (DEC3)
unnamed: C3.1, L1.1, U1.P$H23 (ANT)
unnamed: C1.1, U1.P$B24 (XC1), X1.1
unnamed: C2.1, U1.P$A23 (XC2), X1.3
unnamed: C20.1, U1.P$AC5 (DEC3V3)
unnamed: C9.1, U1.P$N24 (DEC5)
unnamed: C14.1, U1.P$B1 (VDD)
unnamed: L2.1, U1.P$B3 (DCC)
unnamed: L2.2, L3.1
unnamed: C13.1, U1.P$A18 (DEC2)
unnamed: C12.1, U1.P$A22 (VDD)
unnamed: IC3.1 (SDO), R3.2
unnamed: IC9.D1 (SCL), R4.2
unnamed: IC9.E1 (SDA), R2.2
unnamed: R17.1, R18.1
unnamed: IC1.D1 (TS/MR), R9.2
unnamed: C2-EP-DR.2, D5.2 (A), L5.2, Q3.3 (D)
unnamed: C2-EP-DR.1, D2.1 (K), D4.2 (A)
unnamed: R1_EP_DR.1, R_TYPE_SEL.2, SJ1.2
unnamed: EPD_C2.2, J1.4
unnamed: EPD_C1.2, J1.5
unnamed: EPD_C6.2, J1.18
unnamed: EPD_C7.2, J1.19
unnamed: EPD_C8.2, J1.20
unnamed: EPD_C10.2, J1.22
unnamed: EPD_C12.2, J1.24
unnamed: C32.2, IC2.A2 (REG)
unnamed: J4.A5 (CC1), R1_USB.2
unnamed: J4.B5 (CC2), R2_USB.1
OUT: IC2.C3 (OUT-)
OUT+: IC2.A3 (OUT+), TP_OP.TP
OUT-: TP_ON.TP
P0.00/XL1: C17.2, U1.P$D2 (P0.00/XL1), X2.1
P0.01/XL2: C18.2, U1.P$F2 (P0.01/XL2), X2.2
P0.04: U1.P$J1 (P0.04/AIN2)
P0.09: U1.P$L24 (P0.09/NFC1)
P0.13/1.5D: C30.2, R5.1, SW_UP.2
P0.14/1.5D: C31.2, R8.1, SW_ENT.2
P0.26: U1.P$G1 (P0.26)
P0.27: U1.P$H2 (P0.27)
P0.28: U1.P$B11 (P0.28/AIN4)
P0.29: U1.P$A10 (P0.29/AIN5)
P0.30: U1.P$B9 (P0.30/AIN6)
P0.31: U1.P$A8 (P0.31/AIN7)
P1.01/1.6C: Q1.1 (G), R_PWR_EPD.1
P1.01/2.4B: U1.P$Y23 (P1.01)
P1.02/1.6C: C29.2, R7.1, SW_DN.2
P1.02/2.8C: U1.P$W24 (P1.02)
P1.03: U1.P$V23 (P1.03)
P1.04: U1.P$U24 (P1.04)
P1.05: U1.P$T23 (P1.05)
P1.06: U1.P$R24 (P1.06)
P1.07: U1.P$P23 (P1.07)
P1.09: U1.P$R1 (P1.09)
P1.10: U1.P$A20 (P1.10)
P1.11: U1.P$B19 (P1.11)
P1.12: U1.P$B17 (P1.12)
P1.13: U1.P$A16 (P1.13)
P1.14: U1.P$B15 (P1.14)
P1.15: U1.P$A14 (P1.15)
PMIC_INT: IC1.A1 (!INT), U1.P$T2 (P0.11)
PO.13/2.6C: U1.P$AD8 (P0.13)
PO.14/2.7C: U1.P$AC9 (P0.14)
PO.19: U1.P$AC15 (P0.19)
PO.20: U1.P$AD16 (P0.20)
PO.21: U1.P$AC17 (P0.21)
PO.22: U1.P$AC19 (P0.23)
PO.24: U1.P$AD20 (P0.24)
PO.25: U1.P$AC21 (P0.25)
PREVGH: D5.1 (K), EPD_C9.2, J1.21
PREVGL: D2.2 (A), EPD_C11.2, J1.23
RESE: J1.3, Q3.2 (S), R1_EP_DR.2
RESET: J2.6, TP_RESET.TP, U1.P$AC13 (P0.18/RESET)
RF: ANT1.1 (FEED), C4.1, C22.1, L1.2
SCK/1.5B: J1.13
SCK/2.2D: U1.P$A12 (P0.02/AIN0)
SCL/1.4C: IC2.C1 (SCL)
SCL/2.4C: IC1.B1 (SCL), R4.1, R17.2, TP_SCL.TP, U1.P$M2 (P0.07), U3.7 (SCL)
SDA/1.4C: IC2.B2 (SDA)
SDA/2.4C: IC1.C1 (SDA), IC3.2 (SDX), R2.1, R18.2, TP_SDA.TP, U1.P$L1 (P0.06), U3.8 (SDA)
SWDCLK: J2.4, TP_SWDCLK.TP, U1.P$AA24 (SWDCLK)
SWDIO: J2.2, TP_SWDIO.TP, U1.P$AC24 (SWDIO)
SWO: TP_SWO.TP, U1.P$AD22 (P1.00)
VBAT/1.2A: C27.2, TP_VBAT.TP, U3.2 (CELL), U3.3 (VDD)
VBAT/2.5C: C37.2, IC1.C2 (BAT)
VBUS/1.5D: C42.1, C43.1, D3.5 (VBUS), J4.A4_B9 (VBUS), J4.A9_B4 (VBUS)
VBUS/2.6D: C21.1, C38.2, IC1.A2 (IN), U1.P$AD2 (VBUS)
VREG: C23.2, C24.2, C39.1, IC1.B2 (SYS), IC9.A1 (EN), IC9.A2 (VIN_1), IC9.A3 (VIN_2), TP_VREG.TP

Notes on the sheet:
SWD
IMU
DC/DC
LIPo Charger
E-Paper Drive Circuit
0.47
2.2
10K
DMG2305UX-7
10k
E-Paper Display Connector
Buttons
Haptic Driver
Fuel Gauge
0.1uF
5K1
USB C Connector & ESD Protection
MCU, Power, IMU, SWD
E-Paper & Peripherals
drawn by: Mantu Ionut
N.C

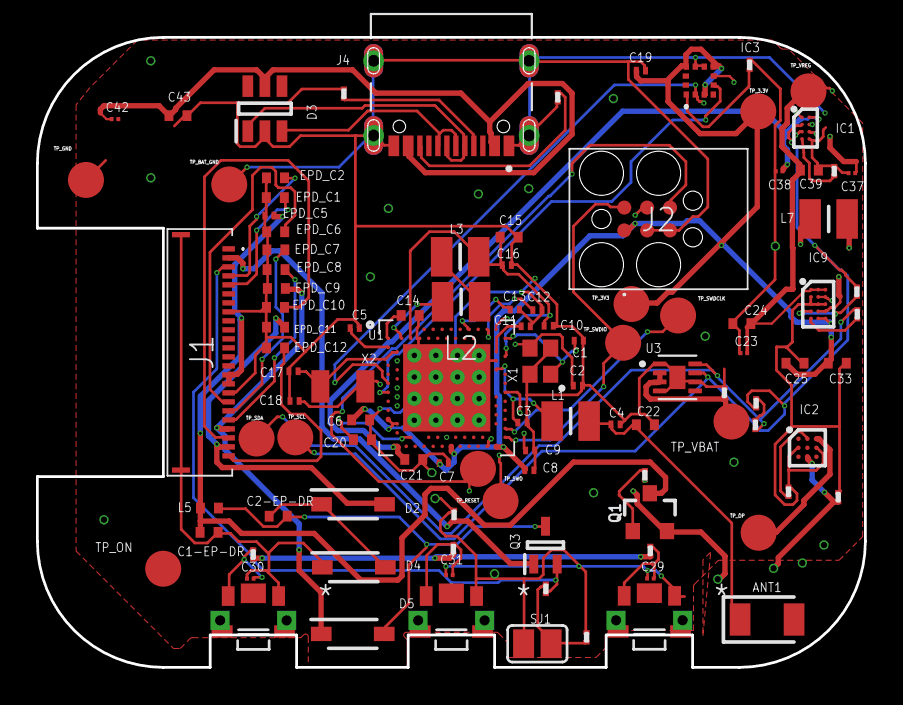
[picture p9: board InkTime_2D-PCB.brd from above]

Board: 4 copper layers, 46.0 x 35.0 mm, 105 parts (0 on the bottom side), 66 nets.

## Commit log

2026-04-10 Added the entire project
    [InkTime Schematic.sch, InkTime_2D-PCB.brd, InkTime_Complete_Device.f3z]
2026-04-13 Reuploaded Bom and Cpl files as they had a problem where they couldn't be opened when transformed to .csv
2026-04-17 Completed README, added 3D models to all the components and solved a problem with the ground plane
    [InkTime_2D-PCB.brd, InkTime_Complete_Device.f3z]
2026-04-20 Added Via Stiching to GND planes
    [InkTime_2D-PCB.brd]
2026-04-22 Modified Complete Device
    [InkTime_Complete_Device.f3z]
2026-04-22 Modified PCB
    [InkTime_2D-PCB.brd]

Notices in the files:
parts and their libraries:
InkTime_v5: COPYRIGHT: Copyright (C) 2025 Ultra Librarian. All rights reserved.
